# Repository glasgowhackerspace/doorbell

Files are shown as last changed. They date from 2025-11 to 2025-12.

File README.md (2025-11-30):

# Glasgow Hackerspace Doorbell Bot

A Discord bot to ring a bell in the Glasgow Hackerspace when `@doorbell` is mentioned.
The code is written in Python and designed to run on a Raspberry Pi Zero 2W.

## Hardware setup
 - A [Waveshare 2.13" e-paper display](https://www.waveshare.com/2.13inch-e-paper-hat.htm) is attached directly to the GPIO header on the pi, or as described in their [documentation](https://www.waveshare.com/wiki/2.13inch_e-Paper_HAT_Manual#Working_With_Raspberry_Pi).
 - An [SG90 servo motor](http://www.ee.ic.ac.uk/pcheung/teaching/DE1_EE/stores/sg90_datasheet.pdf) is wired to 5v, GND, and [pin 7 (GPIO 4)](https://pinout.xyz/pinout/pin7_gpio4/) on the Pi. If the e-paper display is attached to the front of the GPIO header, then these connections must be made on the rear.
 - A push-button is wired between [pin 5 (GPIO 3)](https://pinout.xyz/pinout/pin5_gpio3/) and GND.

`.stl` files for a frame to mount the bell, and a stand to mount the servo are included under the [3d_files](./3d_files) directory. Everything was mounted into an [IKEA VÄSTANHED](https://www.ikea.com/gb/en/p/vaestanhed-frame-black-00479218/) photo frame.

## Software Setup
Deploying this project to a pi has been automated with Ansible. See [deploy.md](./ansible/deploy.md).

The bot requires a token to access the Discord API.
You need a Discord dev account to generate this token: https://discord.com/developers/
Once generated, these details should be entered into a `.env` file following the format of the [.env.template](.env.template) file in this repo.

If you don't want to use Ansible the following steps should achieve the same thing.

### Manual setup
```
# create a new user, add it to the required groups
useradd -m ding
usermod -a -G gpio,spi ding
# clone the code into the ding users home directory
su ding
cd /home/ding
git clone --recurse-submodules https://github.com/glasgowhackerspace/doorbell.git
# set up the python environemnt and dependencies
cd doorbell
python3 -m venv .venv
source .venv/bin/activate
pip3 install -r requirements.txt
# configure the services
su <your normal username>
pigpiod
ln -s /home/ding/doorbell/doorbell_bot.service /etc/systemd/system/doorbell_bot.service
systemctl enable doorbell_bot
systemctl start doorbell_bot
# if you want the shutdown button to work
echo "dtoverlay=gpio-shutdown" | sudo tee -a /boot/firmware/config.txt
reboot
```

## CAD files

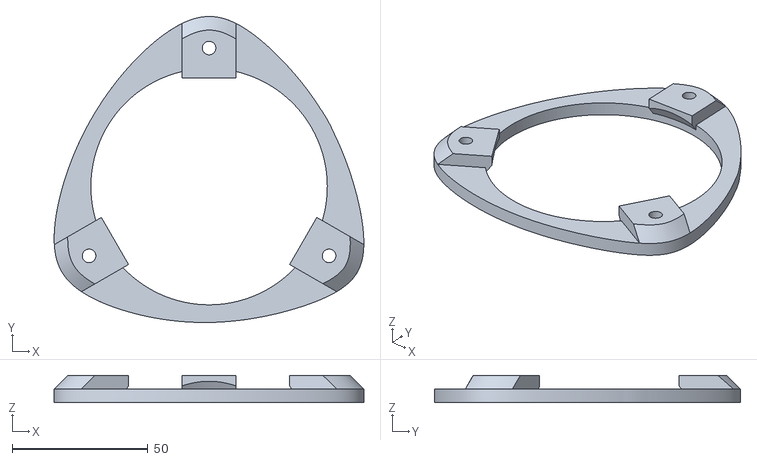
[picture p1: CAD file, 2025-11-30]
3d_files/GlasHack_doorbell_frame.stl
114.0 x 112.6 x 10.0

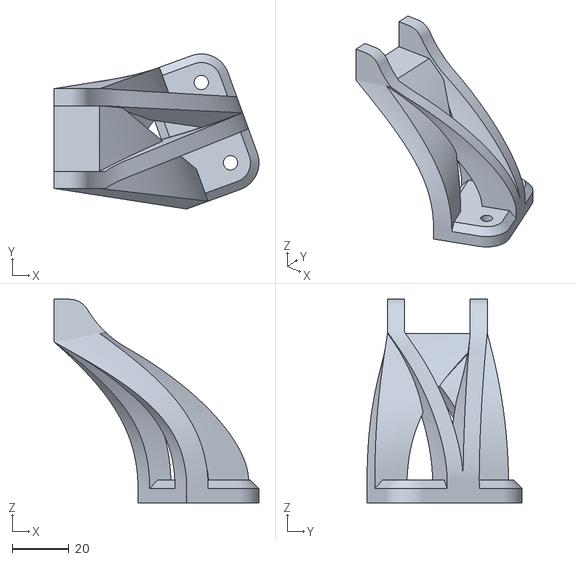
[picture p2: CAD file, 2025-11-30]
3d_files/GlasHack_doorbell_stand.stl
71.9 x 54.4 x 71.4

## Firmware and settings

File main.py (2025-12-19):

#!/usr/bin/env python
from datetime import datetime as dt
import logging
import os
import sys
import time
import asyncio
# for discord bot
import discord
import dotenv
# to control servo motor
import pigpio
# to write to e-paper display
from PIL import Image,ImageDraw,ImageFont
import epaper

logger = logging.getLogger(__name__)
logging.basicConfig(level=logging.WARNING)
discord.VoiceClient.warn_nacl = False

EP = epaper.epaper("epd2in13_V4")
# GPIO 4, header pin 7
SERVO_PIN = 4
pwm = None
epd = None

dotenv.load_dotenv()

intents = discord.Intents.default()
intents.message_content = True

client = discord.Client(intents=intents)

FONT_FILE = "AtkinsonHyperlegibleMonoVF-Variable.ttf"
FONT15 = ImageFont.truetype(FONT_FILE, size=15, encoding="unic")
FONT15.set_variation_by_name("ExtraBold")
FONT24 = ImageFont.truetype(FONT_FILE, size=24, encoding="unic")
FONT24.set_variation_by_name("ExtraBold")


def main():
    global pwm
    global epd
    pwm = pigpio.pi()
    pwm.set_mode(SERVO_PIN, pigpio.OUTPUT)
    pwm.set_PWM_frequency(SERVO_PIN, 50)

    try:
        epd = EP.EPD()
        epd.init()
        display_message("d[•_•]b", "Listening for @doorbell mentions on Discord")
    except Exception as e:
        logger.warning("unable to interact with the e-paper display")
        logger.warning(e)

    client.run(os.getenv("DISCORD_BOT_TOKEN"))


@client.event
async def on_message(message: discord.Message):
    if message.author == client.user:
        return

    logger.debug(f"detected message: [{message}] role_mentions: [{message.role_mentions}] mentions: [{message.mentions}] content: [{message.clean_content}]")

    if user_mentioned("doorbell", message) or role_mentioned("doorbell", message):
        logger.info(f"{message.author.name} mentioned @doorbel [{message.clean_content}]")

        # await the following tasks together
        async with asyncio.TaskGroup() as tg:
            tg.create_task(ring_bell())
            tg.create_task(message.add_reaction("🔔"))

        if epd:
            display_message(message.author.nick or message.author.global_name or message.author.name, message.clean_content)


def get_wrapped_text(text: str, font: ImageFont.ImageFont, line_length: int):
    lines = [""]
    for word in text.split():
        line = f"{lines[-1]} {word}".strip()
        if font.getlength(line) <= line_length:
            lines[-1] = line
        else:
            lines.append(word)
    return "\n".join(lines)


def role_mentioned(role: str, message: discord.Message) -> bool:
    return any([r.name == role for r in message.role_mentions])


def user_mentioned(username: str, message: discord.Message) -> bool:
    return any([username == u.name for u in message.mentions])


def display_message(heading: str, body: str):
    epd.init() # wake the display from sleep
    image = Image.new("1", (epd.height, epd.width), 255)
    draw = ImageDraw.Draw(image)
    draw.text((0, 0), heading, font=FONT24, fill=0)
    time = dt.strftime(dt.now(), "%H:%M")
    line = get_wrapped_text(f"[{time}] {body}", FONT15, epd.height)
    draw.text((0, 35), line, font=FONT15, fill=0)
    epd.display(epd.getbuffer(image))
    epd.sleep()


async def ring_bell():
    pwm.set_servo_pulsewidth(SERVO_PIN, 500)
    await asyncio.sleep(0.3)
    pwm.set_servo_pulsewidth(SERVO_PIN, 2500)


if __name__ == "__main__":
    try:
        main()
    finally:
        logger.info("running cleanup")
        if pwm:
            pwm.set_PWM_dutycycle(SERVO_PIN, 0)
            pwm.set_PWM_frequency(SERVO_PIN, 0)
        if epd:
            display_message("(-.-) Zzz", "Sleeping")
            EP.epdconfig.module_exit(cleanup=True)

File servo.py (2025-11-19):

import time
import pigpio

SERVO_PIN = 4

def main():
    pwm = pigpio.pi()
    pwm.set_mode(SERVO_PIN, pigpio.OUTPUT)
    pwm.set_PWM_frequency(SERVO_PIN, 50)

    pwm.set_servo_pulsewidth(SERVO_PIN, 500)
    time.sleep(0.3)
    pwm.set_servo_pulsewidth(SERVO_PIN, 2500)
    time.sleep(0.5)

    pwm.set_PWM_dutycycle(SERVO_PIN, 0)
    pwm.set_PWM_frequency(SERVO_PIN, 0)


if __name__ == "__main__":
    main()

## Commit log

2025-11-17 Move to pigpio and add e-paper display
    The pigpio module provides more stable PWM timing than RPi.GPIO.
    This prevents constant servo 'jittering'.
    A Waveshare e-paper display using the library provided by Waveshare (in
    a git submodule) has been added to display some basic information about
    the @keyholder messages that have been received.
    [main.py, servo.py]
2025-11-19 Fix issues with mentions and username display
    [main.py, servo.py]
2025-11-30 add ansible, .stl files and update README
    [GlasHack_doorbell_frame.stl, GlasHack_doorbell_stand.stl]
2025-12-13 fixes for new pi OS changes
    [main.py]
